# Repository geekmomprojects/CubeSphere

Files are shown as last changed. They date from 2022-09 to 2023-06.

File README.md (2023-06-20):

# The Cube Orb Project

Design files and code for a 3D printed shell to transform an LED cube of off-the shelf matrices into an illuminated sphere.

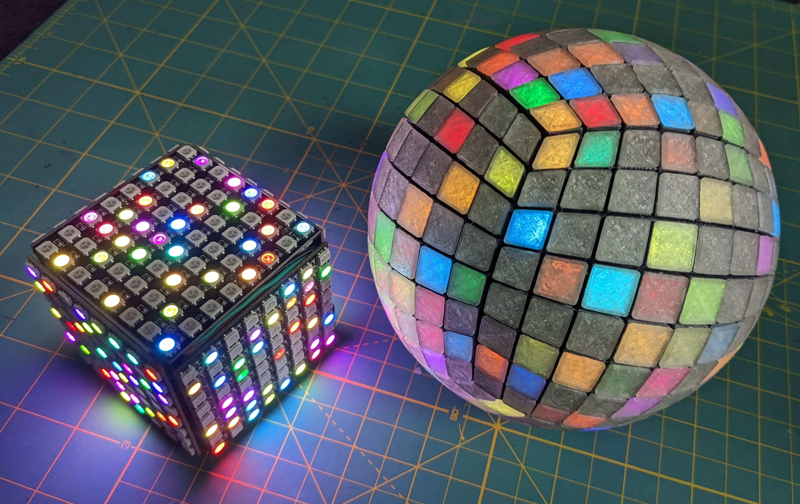
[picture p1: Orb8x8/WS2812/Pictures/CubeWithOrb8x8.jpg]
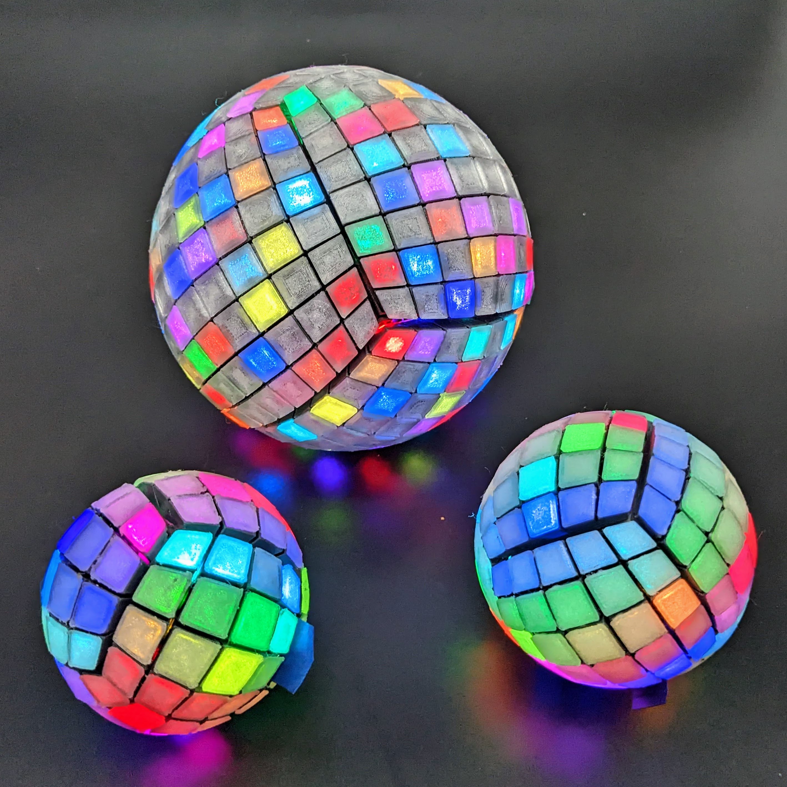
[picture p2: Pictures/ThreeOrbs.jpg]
 | 

There are multiple versions of ths project which use off-the shelf matrices of different sizes. Most use WS2812 addressable LEDs, but one version of the 8x8 orb uses SK9822 matrices. The 5x5 Orb is written up in great detail in Make: Magazine, vol. 84.

The designs, which exist in varying degrees of completion are:
- [4x4 WS2812 matrices V1](https://github.com/geekmomprojects/CubeSphere/tree/main/Orb4x4) (challenging)
- [4x4 WS2812 matrices V2 with 3D printed battery holder](https://github.com/geekmomprojects/CubeSphere/tree/main/Orb4x4_V2) (challenging)
- [5x5 WS2812 matrices](https://github.com/geekmomprojects/CubeSphere/tree/main/Orb5x5) (intermediate)
- [8x8 WS2812 matrices](https://github.com/geekmomprojects/CubeSphere/tree/main/Orb8x8/WS2812) (challenging)
- [8x8 SK9822 (APA102 equivalent) matrices](https://github.com/geekmomprojects/CubeSphere/tree/main/Orb8x8/SK9822) (intermediate)

The 8x8 orbs both use the [Pixelblaze Controller](https://electromage.com/pixelblaze) and its associated sensor board to generate pixel-mapped LEDs patterns that are sound/motion responsive. The other orb designs use the [XIAO Sense nRF52840 board](https://www.seeedstudio.com/Seeed-XIAO-BLE-Sense-nRF52840-p-5253.html) with custom CircuitPython code to control the LEDs.

For all designs, it is strongly recommended that you 3D print the cube interior connectors in PETG or other similarly strong filament. The exterior shell may be printed in PETG or PLA. You will need a well-tuned printer with good bed adhesion for this project, especially for the translucent diffusing tiles, as they require printing a large quantity of tiny parts.

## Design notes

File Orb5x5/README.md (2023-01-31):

These are design files for Cube Orb using 5x5 LED matrices. This build is documented in great detail in Vol. 84 of Make: magazine

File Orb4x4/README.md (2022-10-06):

# Cube Orb 4x4
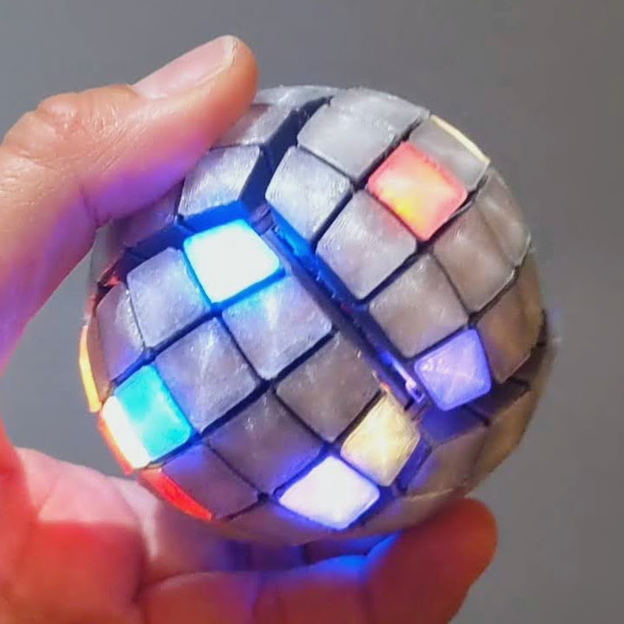
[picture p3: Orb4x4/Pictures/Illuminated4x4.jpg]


Please note that this is NOT a detailed tutorial. I have included as much information as I can to help others build
this project, but the design may still evolve, and there is likely room for improvement. It is a challenging build
because the space inside the matrix cube does not leave much room for soldering or electronics. Careful wire
management and good soldering skills will be required.

For this build, you will need the following materials:
- (6x) 4x4 WS2812 addressable LED matrices (available on Amazon or AliExpress). Size: approx 30mm square, mounting holes 15mm spacing.
- 5mm M2 flathead screws and M2 nuts
- 3D printer filament (PETG recommended for strength, I haven't tried PLA). Translucent clear filament for the tiles, and opaque filament for the shells.
- Small controller (Adafruit QtPy or Seeeduino XIAO are good choices)
- Small LiPo or LiIon battery to fit inside the matrix compartment. The largest battery I could fit inside was 250 mAh. There is also the possibility of 3D printing a battery holder for a cylindrical LiIon 14250 battery discussed further down.
- Super glue to attach tiles to the shells (Gorilla Glue Super Glue Gel highly recommended)
- Wires/solder to connect the matrices/controller/battery
- (4x) 1/4" by 1/8" disk magnets. Read paragraph below on the magnetic connectors for specifics
- 2mm wide double-sided tape (e.g. [https://www.amazon.com/gp/product/B019OQ4Z10/](https://www.amazon.com/gp/product/B019OQ4Z10/))

Start by printing each of the STL files in the [Design directory](./Design/) in the quantities included in the filename. You can buy standard 4x4 WS2812 LED matrices on Amazon or AliExpress. This design is intended for matrices that are approximately 30mm square with 4 mounting holes spaced about 15mm apart. See the [Pictures directory](/Pictures)  for images showing how the 3D printed connectors attach the matrices together.

Everything should be secured together with **5mm M2 flathead (important)** screws and nuts.

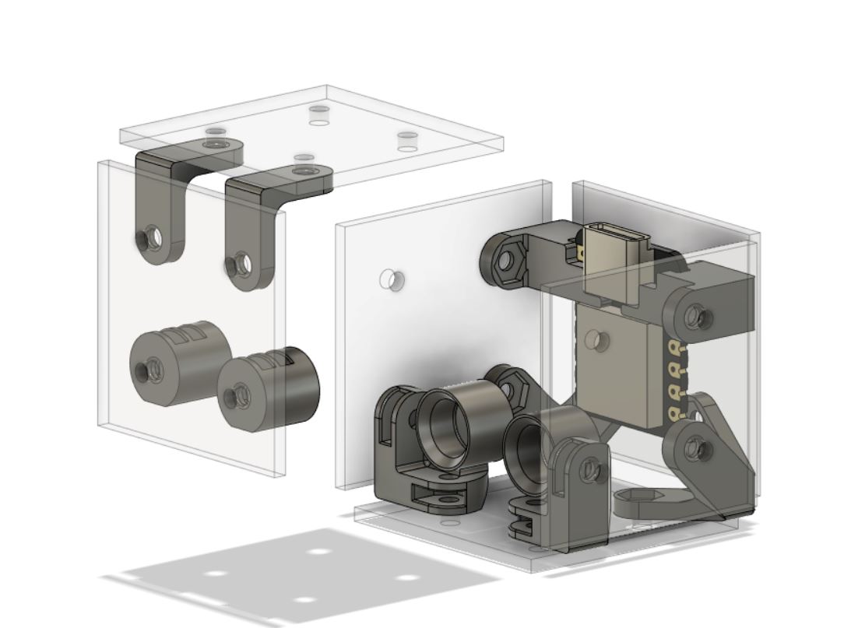
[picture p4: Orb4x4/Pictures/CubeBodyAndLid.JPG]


The supports are designed to hold an Adafruit QtPy or Seeeduino XIA0 controller inside. I am working on CircuitPython code for motion reactive LED animations using the [Seeeduino XIA0 nRF52840 Sense board](https://www.seeedstudio.com/Seeed-XIAO-BLE-Sense-nRF52840-p-5253.html), and will be uploading code to GitHub soon.

The magnetic connectors will latch the body of the cube to the lid, using cylindrical magnets with 1/4" diameter and 1/8" height. I designed the magnet holders to work with these countersunk magnet pairs from K&J magnetics (https://www.kjmagnetics.com/proddetail.asp?prod=R422CS-P-N52&cat=15f), with two pair of magnets per cube. The K&J magnets can be held in place with 5mm or 6mm (better) M2 screws and nuts. However, you can also probably buy standard 1/4" diameter, 1/8" height disk magnets and simply glue them into the holders with superglue. I haven't tried it, but I see no reason it shouldn't work.

Everything except the tiles STL should print well at 0.2mm layer height. The tiles have a bit of overhang near the top where it mushrooms out. I printed those at variable layer height with the shortest layers possible at the overhang, which helped a lot. Since there are 16 individual, small tiles in the tiles STL file, printing it can be tricky. Make SURE your first layer goes down ok. If any one of the tiles lifts off, it will ruin the whole print.

I used PETG for all the printing, because the parts are thin and small. Haven't tried it with PLA. PLA should be ok for the tiles, as they don't support anything but the rest of the pieces are small and/or thin, and will probably benefit from using PETG. Use opaque filament for the shell and transparent filament for the tiles. The brackets/holders can be printed in any color/opacity, as they will not be visible.

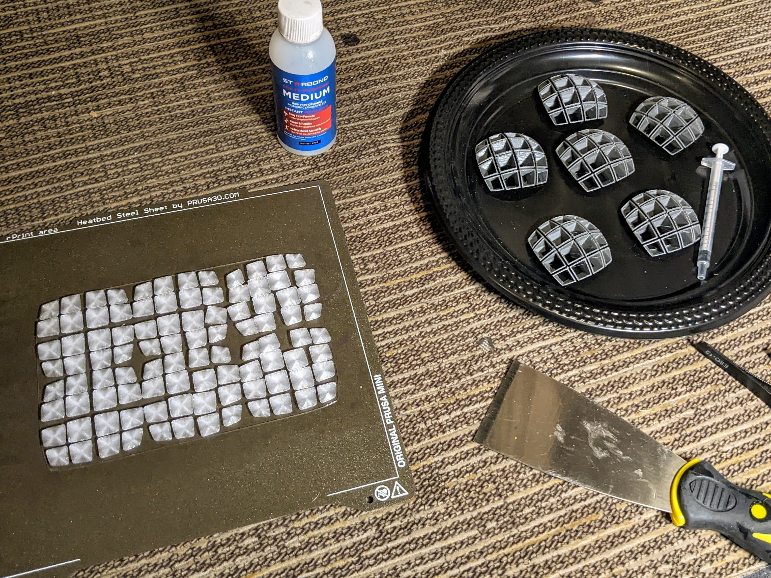
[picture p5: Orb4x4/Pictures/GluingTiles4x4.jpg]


Once printed, glue each of the tiles into the appropriate locations in the shell. Gorilla Glue Super Glue Gel strongly is recommended for this purpose. Put small beads or lines of glue in each of the holes in the top of the shell then insert each tile in the appropriate hole. Don't put the glue directly on the tile, because that's much messier (I speak from experience here!). As the tiles look nearly identical, I strongly recommend leaving them on the print plate until just before gluing each one (I loosened them row by row). Make sure to keep the orientation of each tile straight when you glue them, because it matters and it's easy to get them turned around when you lift them off the plate.

Before attaching the shell pieces to the matrix, connect the matrices into the body of the cube and the lid with the connetors as shown in the images in the [Pictures directory](./Pictures/). There are gaps between the matrices by design, as this leaves more room to put a battery inside the cube. You will probably want to solder wires between the matrices as you connect each one to its assembly because there is not a lot of room to work inside the body of the fully assembled cube.

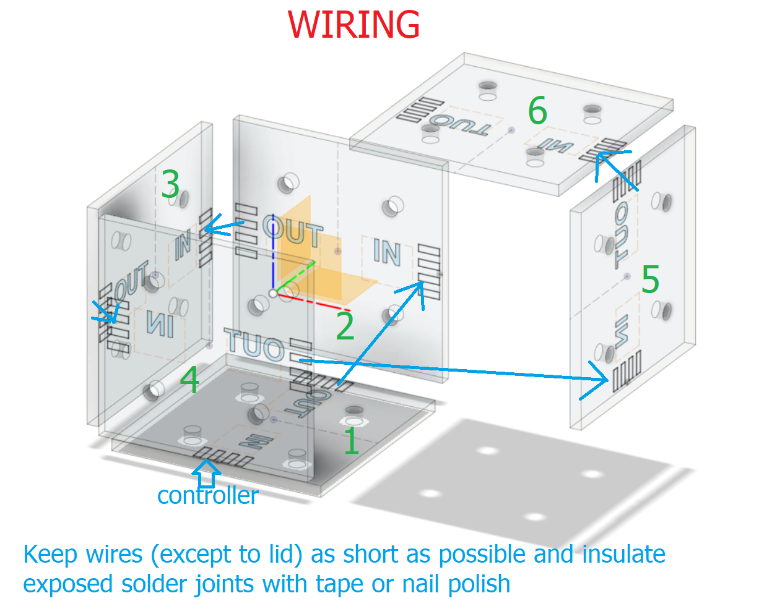
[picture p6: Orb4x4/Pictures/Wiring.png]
 

Once you have fully assembled the body and lid of the cube, you can attach the shell pieces to each matrix (after the glue for the tiles has fully dried). I placed rows and columns of 2mm wide double-sided tape along the bottom of each shell piece, then pressed each one onto a matrix. This works very well, and allows the shells to be removed if necessary. If you are certain that you won't want to remove the shells, then glue should work for this purpose as well. 

A 250 mAh LiPo battery and QTPy-sized controller should fit into the interior of the cube to power everything. Be very careful to cover the exposed pads on the LED matrices (duct tape works for this) so no shorts will occur if a nut or screw becomes loose inside the cube.

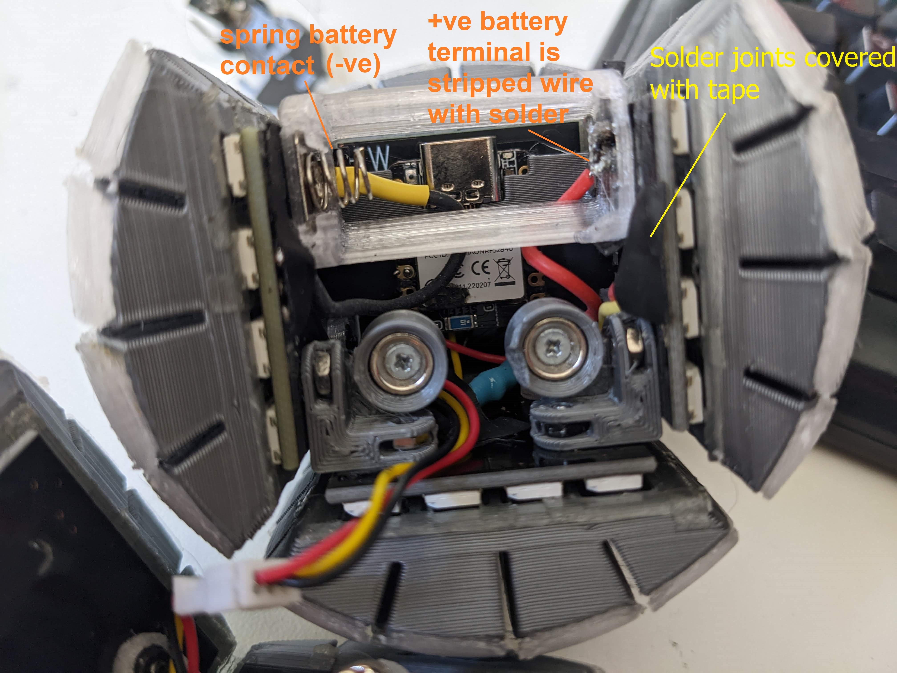
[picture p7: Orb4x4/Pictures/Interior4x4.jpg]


I have also included the (optional) design for a 14250 cylindrical LiIon battery holder which will fit inside the cube as shown in the picture below. This holder is designed to use an AAA battery spring contact no more than 10mm wide (e.g.: https://www.amazon.com/uxcell-Positive-Negative-Conversion-Nickeling/dp/B07HRS5DMC/ref=sr_1_3) for the negative battery terminal and wire wrapped around the hole in the positive terminal to run power to the electronics. More assembly instructions for the battery will follow eventually.
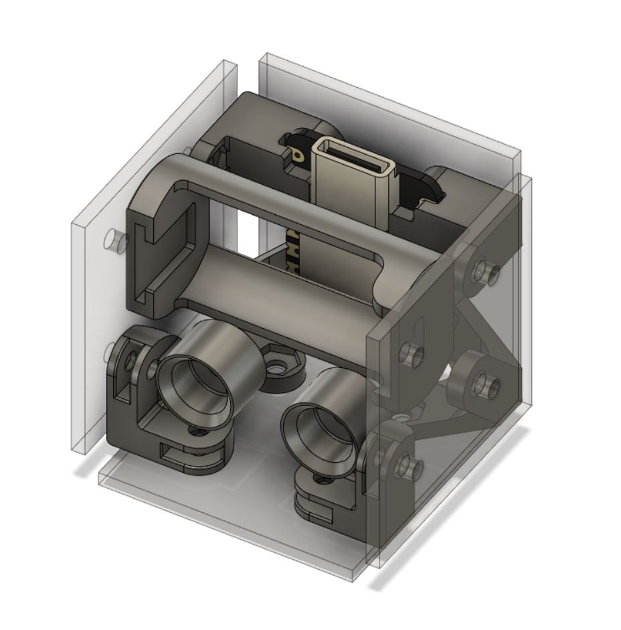
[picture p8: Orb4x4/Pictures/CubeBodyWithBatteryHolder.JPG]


Good luck! Have fun!

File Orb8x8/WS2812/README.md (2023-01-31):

# CubeSphere
Design files and code for a 3D printed shell to transform an LED cube to a sphere. This is a work in progress and the documentation and design are not complete yet. Use at your own peril.

[Follow this link for video of the sphere](https://youtube.com/shorts/eQoiFBxLnEA?feature=share)

Currently the assembly is held together with string wrapped around the parts of the shell to hold them against the matrices.

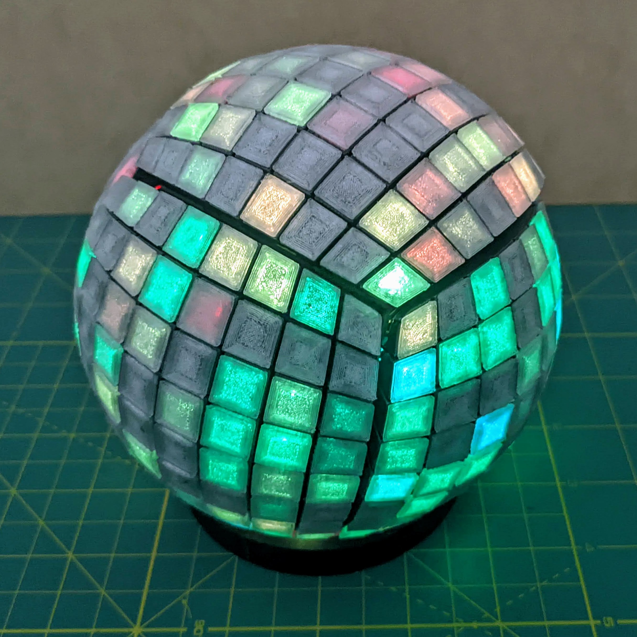
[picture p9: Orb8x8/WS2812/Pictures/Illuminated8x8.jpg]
Partially completed CubeSphere


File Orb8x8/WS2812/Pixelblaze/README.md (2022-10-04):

Please note that the map file here, written for the [Pixelblaze controller] (https://electromage.com/pixelblaze) 
reflects the following layout for the six (zigzag) WS2812 matrices in the base cube. The arrow on each side indicates the direction of the
first row on that matrix.

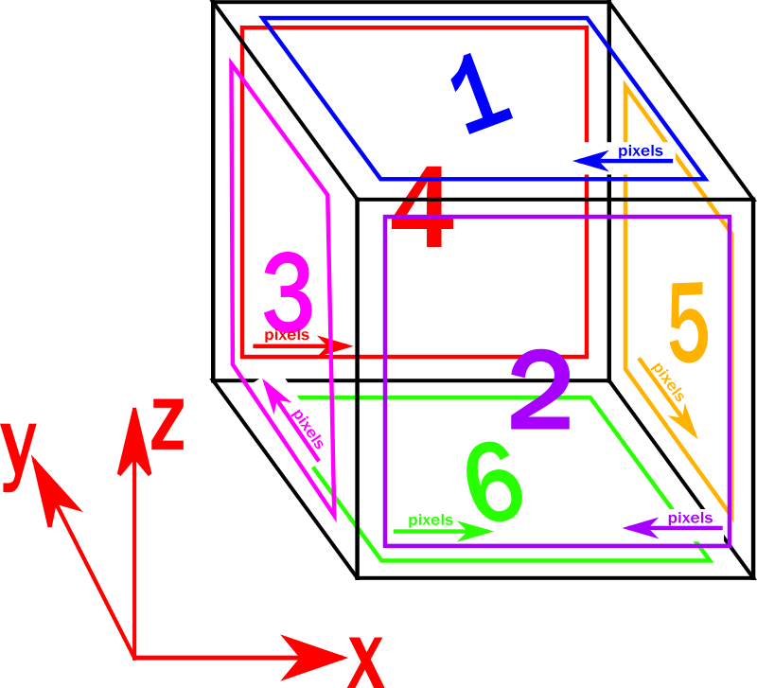
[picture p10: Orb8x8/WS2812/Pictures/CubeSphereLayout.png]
Cube Sphere matrix layout


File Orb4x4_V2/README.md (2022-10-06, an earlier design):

This version of the 4x4 orb is smaller than V1. It requires a 3D printed battery holder for 14250 cylindrical LiIon battery. Assembly instructions are not yet posted for this version.

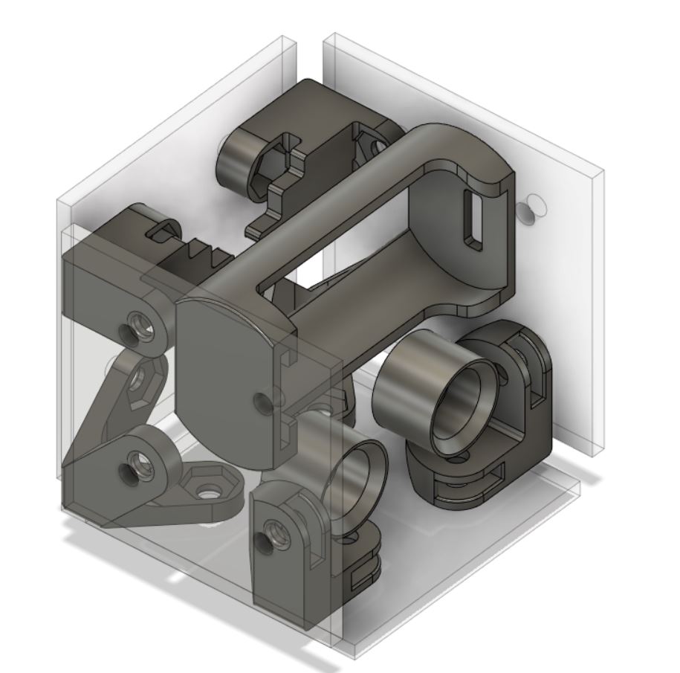
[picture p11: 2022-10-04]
Orb4x4/Pictures/BatteryHolderOrientation.JPG

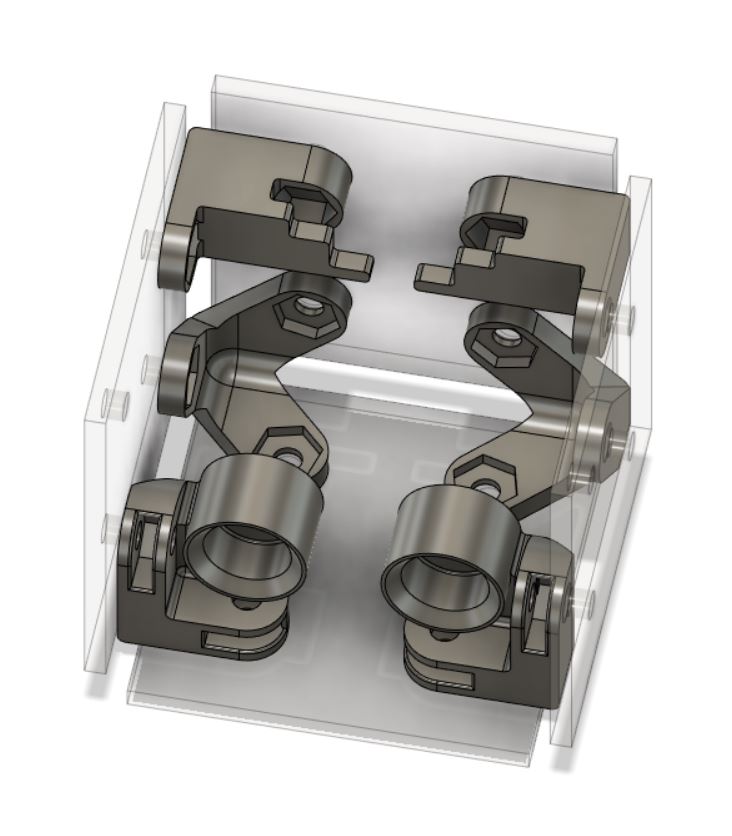
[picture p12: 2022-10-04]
Orb4x4/Pictures/CubebodyWithoutController.JPG

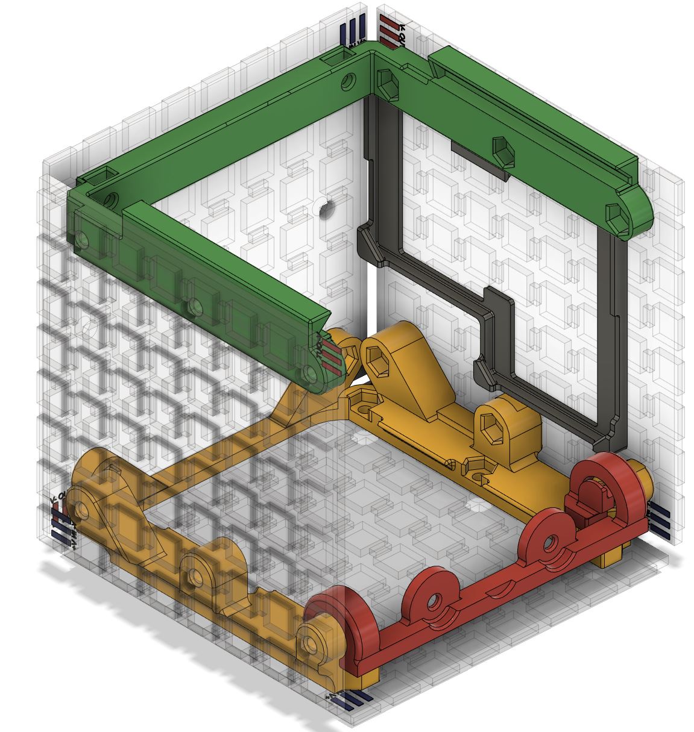
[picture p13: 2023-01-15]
Orb8x8/WS2812/Pictures/MatrixBodyWithBatteryLock.JPG

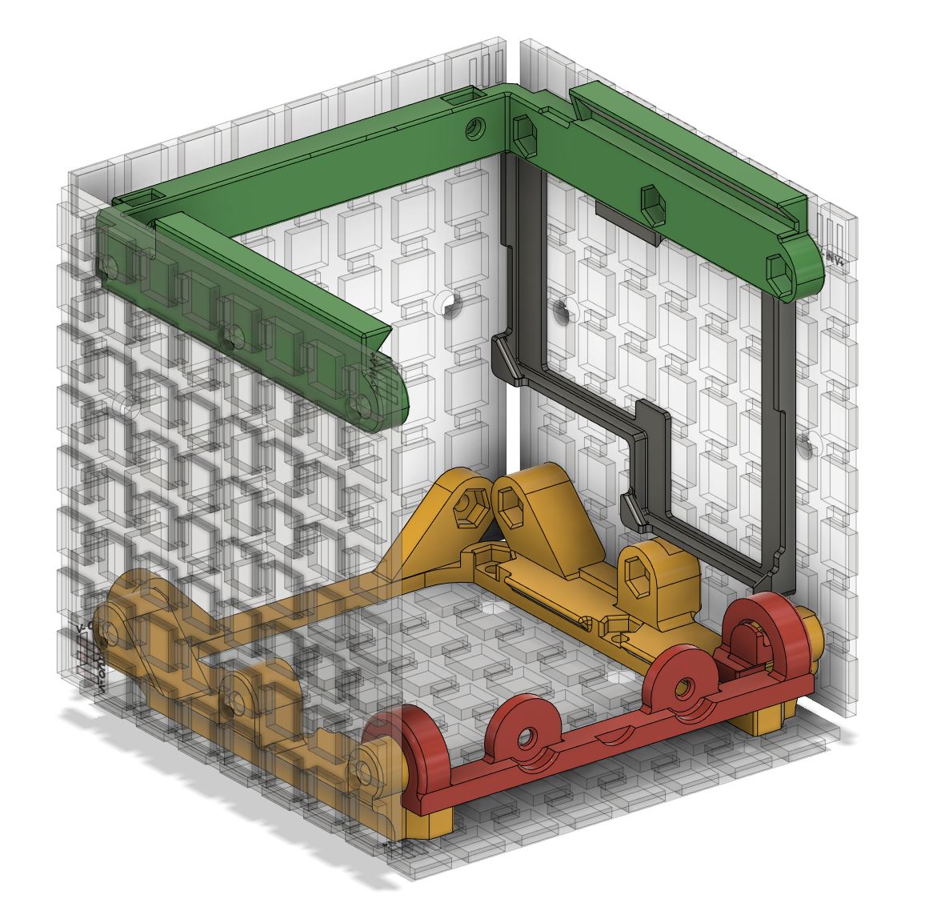
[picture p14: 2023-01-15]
Orb8x8/WS2812/Pictures/MatrixBodyConnectorsWithoutLock.JPG

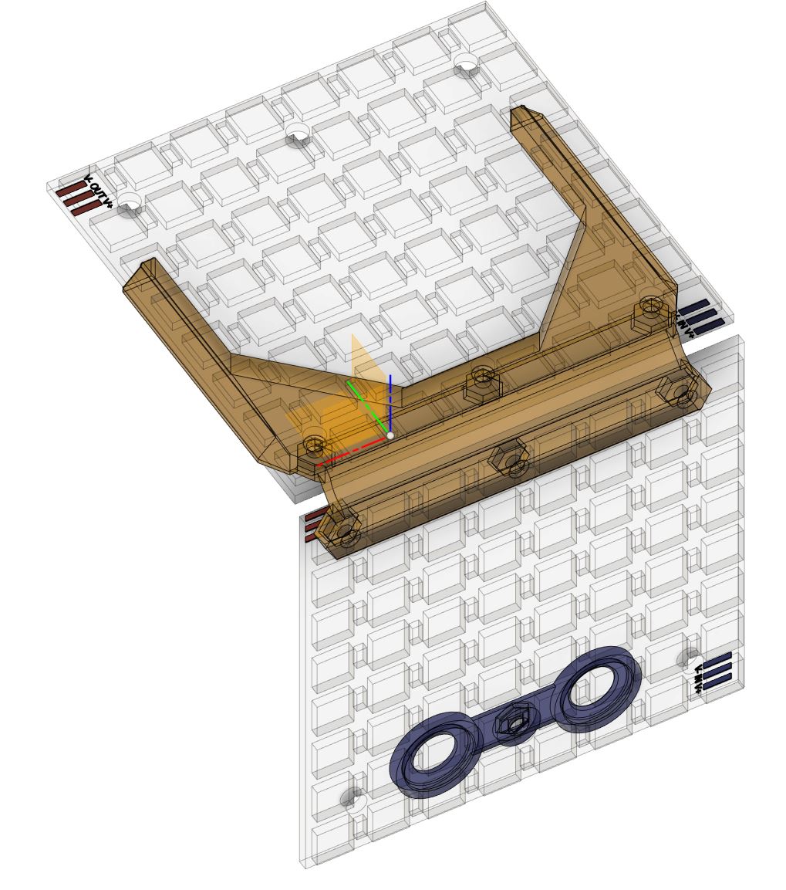
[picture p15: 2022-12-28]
Orb8x8/WS2812/Pictures/MatrixLidWithConnectors.JPG

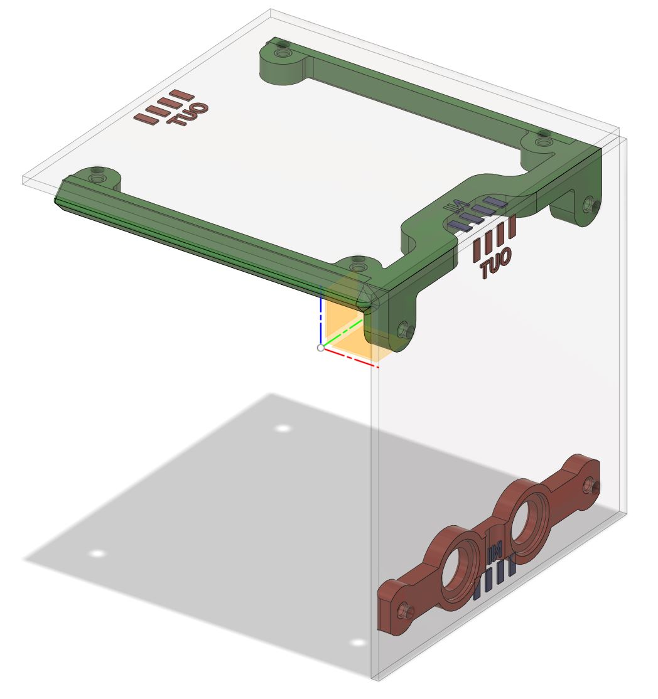
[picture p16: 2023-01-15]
Orb8x8/SK9822/Pictures/MatrixLidWithConnectors.JPG

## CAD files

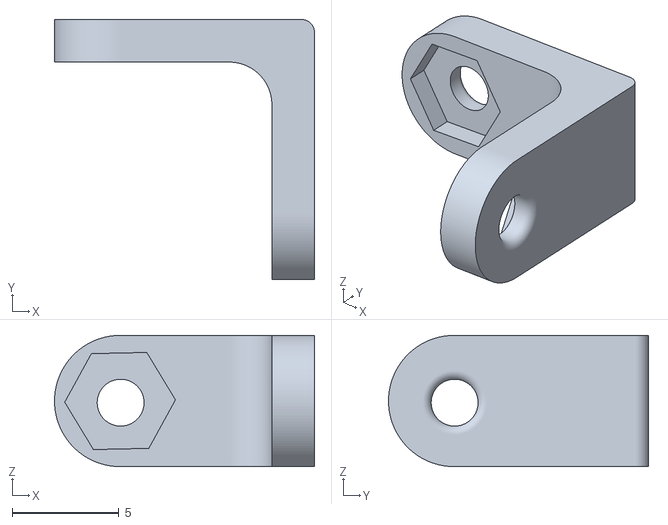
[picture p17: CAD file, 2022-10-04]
Orb4x4/Design/Side Bracket Print_2.stl
12.2 x 12.2 x 6.16

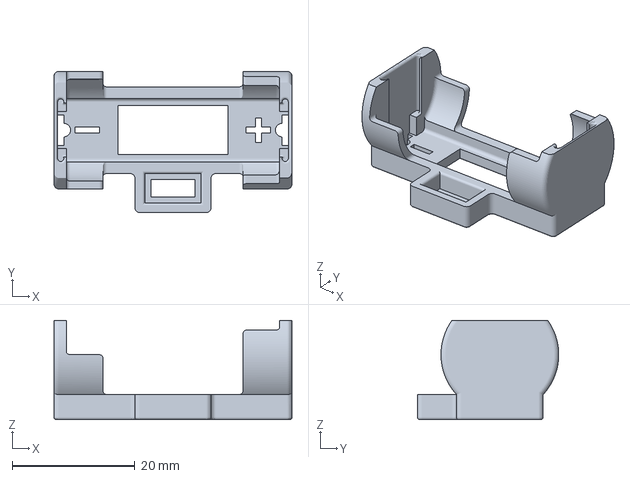
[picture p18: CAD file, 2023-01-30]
Orb5x5/Design/BatteryHolder16340Bambulag.3mf
38.8 x 23.1 x 16.2 mm

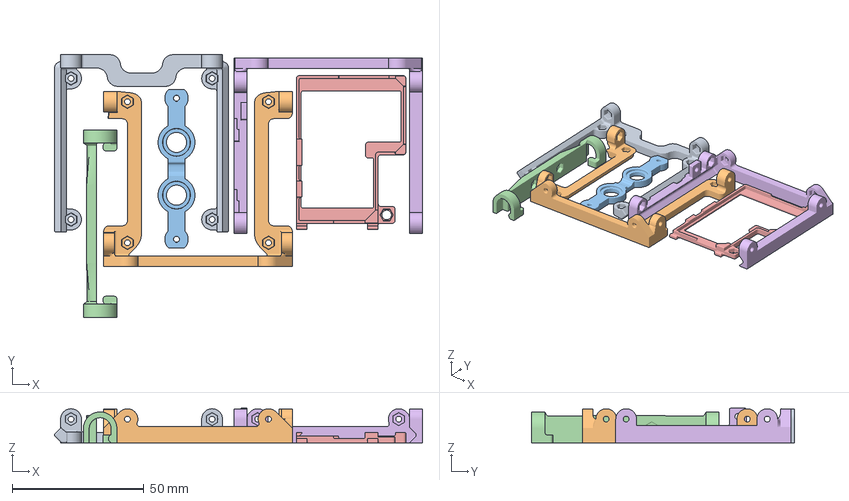
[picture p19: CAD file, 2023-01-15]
Orb8x8/SK9822/Design/CubeSphereSK9822Connectors.3mf
139.5 x 99.6 x 13.2 mm
Orb8x8 with APA102 v116.stl_1
Orb8x8 with APA102 v116.stl_2
Orb8x8 with APA102 v116.stl_3
Orb8x8 with APA102 v116.stl_4
Orb8x8 with APA102 v116.stl_5
Orb8x8 with APA102 v116.stl_6

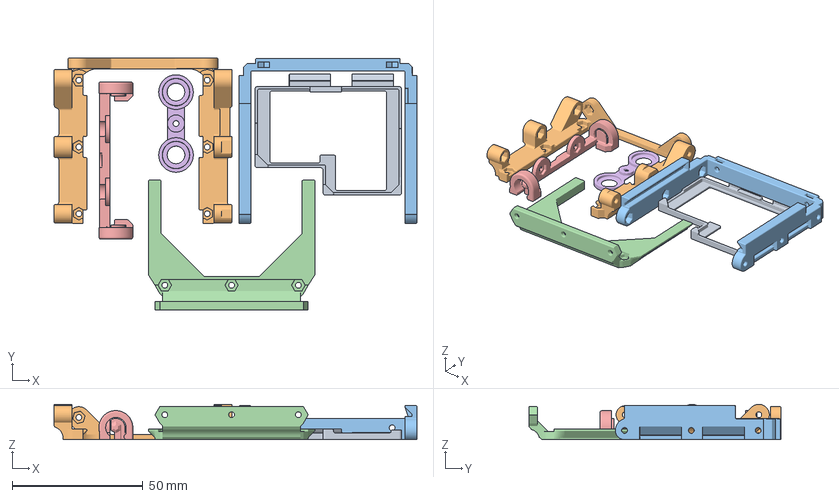
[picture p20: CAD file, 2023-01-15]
Orb8x8/WS2812/Design/CubeSphere8x8WS2812Connectors.3mf
138.6 x 96.3 x 13.5 mm
CubeSphere8x8 v194.stl_1
CubeSphere8x8 v194.stl_2
CubeSphere8x8 v194.stl_3
CubeSphere8x8 v194.stl_4
CubeSphere8x8 v194.stl_5
CubeSphere8x8 v194.stl_6

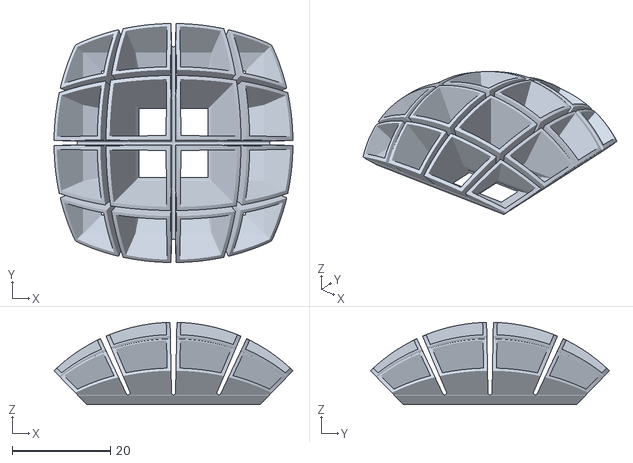
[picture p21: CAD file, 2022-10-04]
Orb4x4/Design/Shell Print_6.stl
48.8 x 48.8 x 16.8

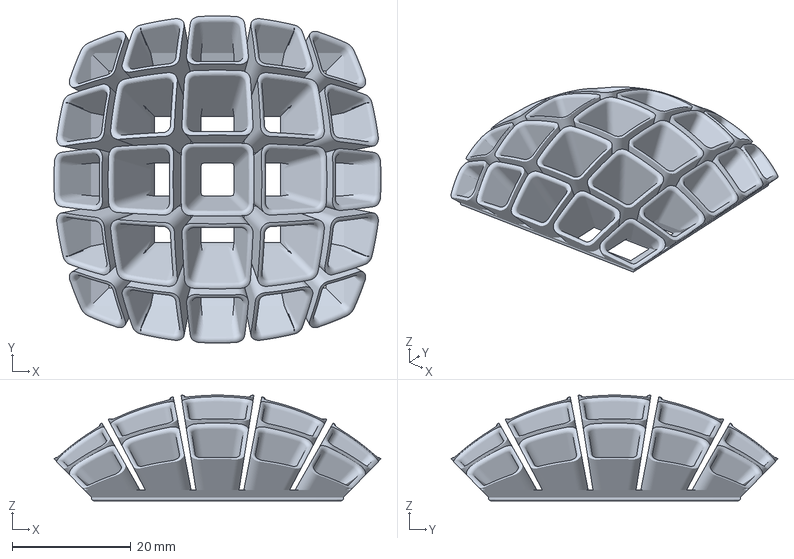
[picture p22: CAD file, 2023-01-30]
Orb5x5/Design/Shell5x5BambulabSlicer.3mf
55.1 x 55.1 x 17.8 mm

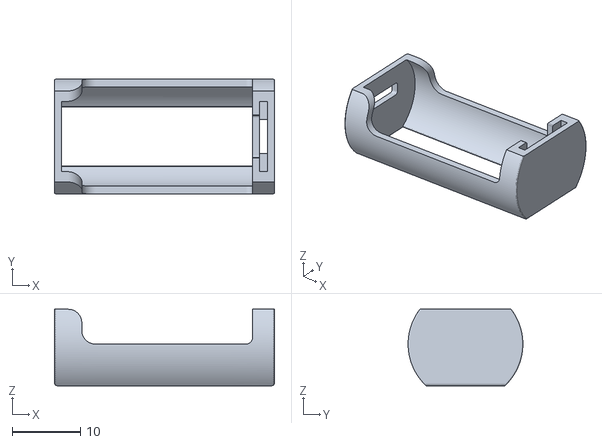
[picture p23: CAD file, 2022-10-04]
Orb4x4/Design/BatteryHolder14250.stl
32.2 x 16.8 x 11.2

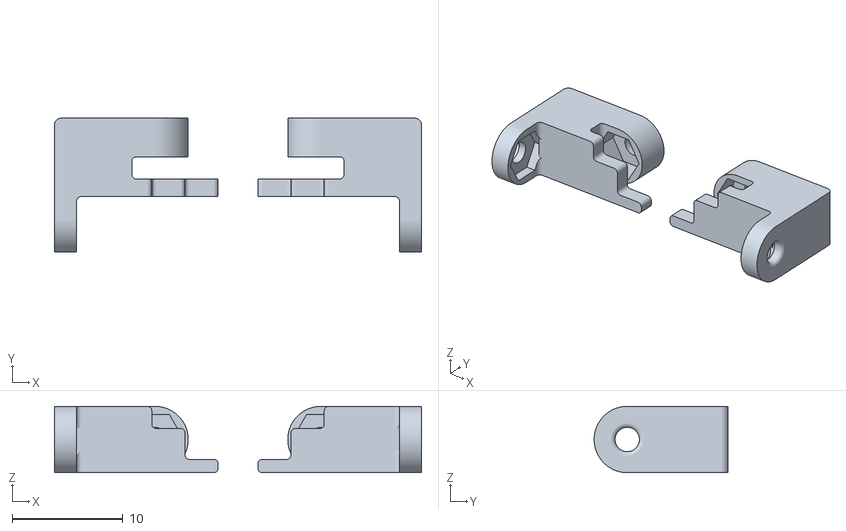
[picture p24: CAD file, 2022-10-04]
Orb4x4/Design/Side Bracket Xiao Holder Print_1.stl
33.2 x 12.1 x 6.00

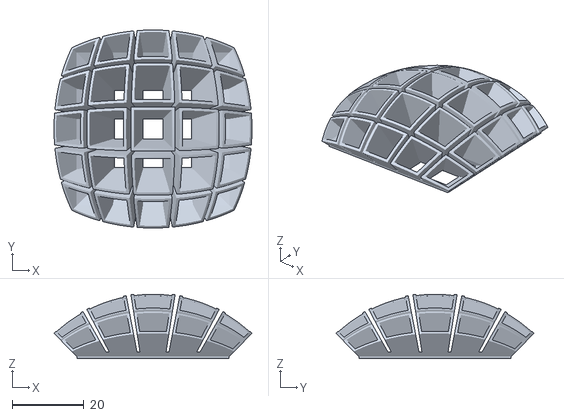
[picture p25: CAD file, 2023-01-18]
Orb5x5/Design/Shell5x5.stl
55.1 x 55.1 x 17.9

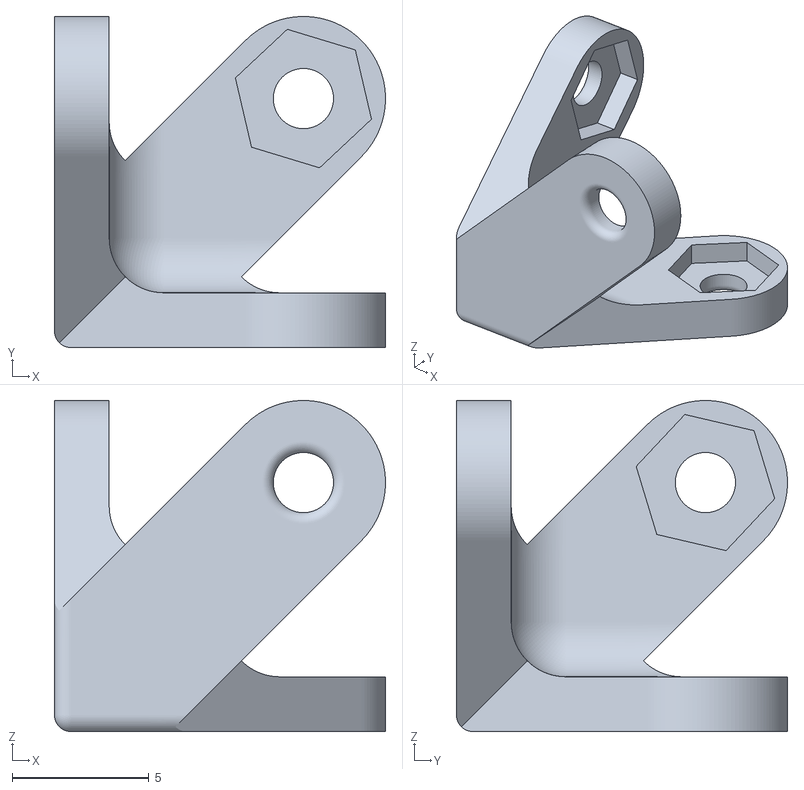
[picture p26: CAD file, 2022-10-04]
Orb4x4/Design/Corner Bracket Print_2.stl
12.1 x 12.1 x 12.1

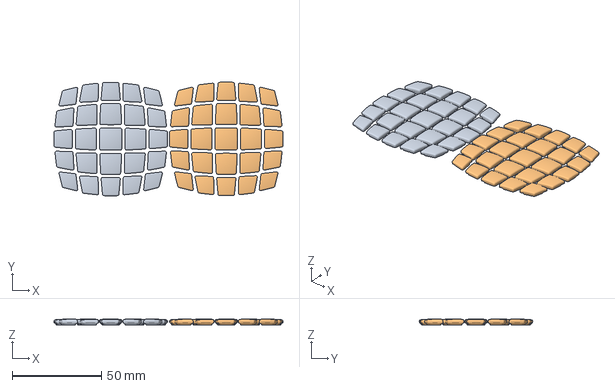
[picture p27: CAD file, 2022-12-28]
Orb5x5/Design/Tiles5x5Thinner.3mf
128.4 x 63.7 x 3.58 mm

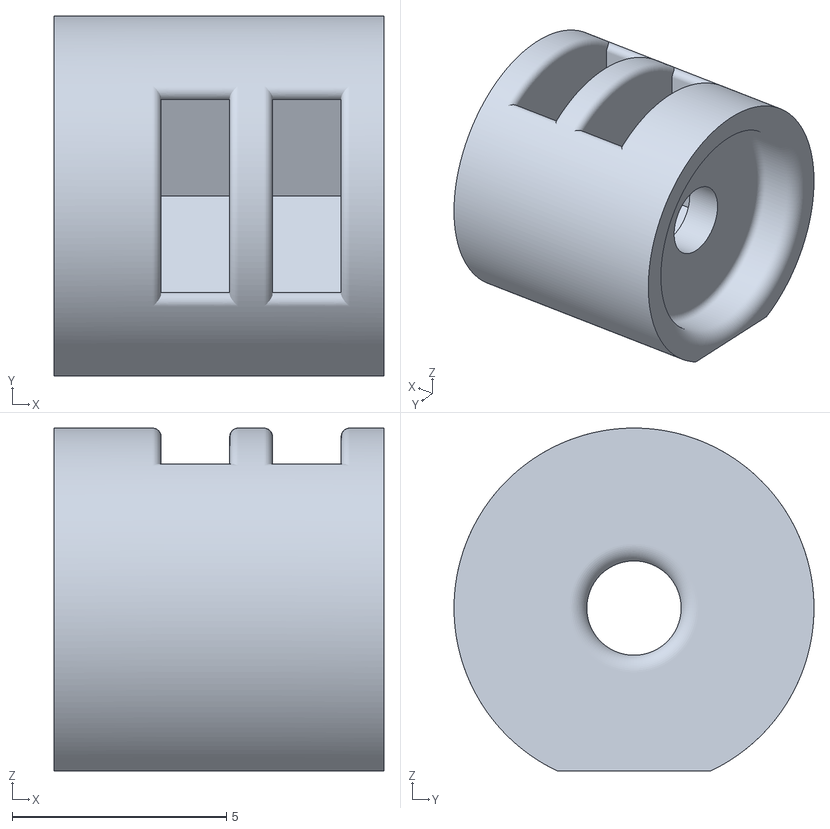
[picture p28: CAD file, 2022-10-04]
Orb4x4/Design/Magnet Holder Lid Print_2.stl
7.70 x 8.40 x 8.00

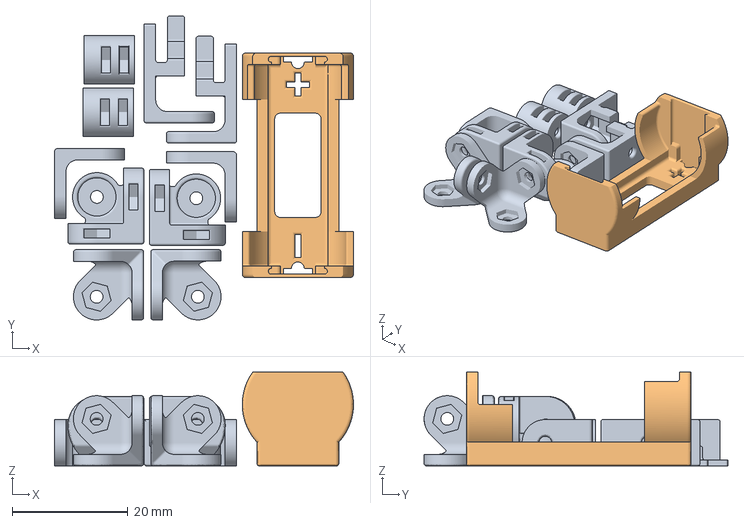
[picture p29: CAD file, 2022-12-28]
Orb5x5/Design/AllConnectors5x5.3mf
51.6 x 52.5 x 16.2 mm
AllConnectors5x5.stl
BatteryHolder16340.stl

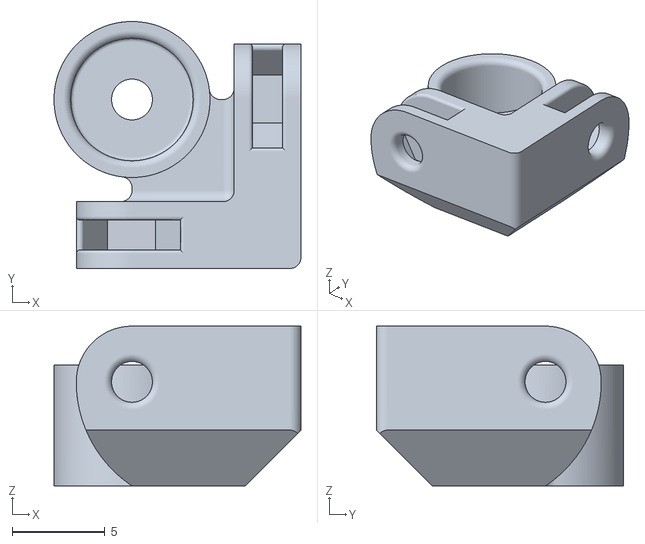
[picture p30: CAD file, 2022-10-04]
Orb4x4/Design/Magnet Holder Body Print_2.stl
13.3 x 13.3 x 8.60

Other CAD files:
Orb5x5/Design/BatteryHolder16340WithSwitch.stl
Orb5x5/Design/BatteryHolder16340.stl
Orb4x4_V2/Design/BatHolder.stl
Orb4x4_V2/Design/Shell4x4V2.stl

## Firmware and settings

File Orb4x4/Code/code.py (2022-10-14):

# Write your code here :-)
from tilt import Tilt
from adafruit_led_animation.animation.rainbowsparkle import RainbowSparkle
from adafruit_led_animation.color import RAINBOW
from bubbles import Bubbles
from orb import *
import imu
import board
import neopixel
import time, random

RED = (255,0,0)
BLACK = (0,0,0)

# Update to match the pin connected to your NeoPixels
pixel_pin = board.D4
# Update to match the number of NeoPixels you have connected
pixel_num = 96

pixels = neopixel.NeoPixel(pixel_pin, pixel_num, brightness=0.3, auto_write=False)
pixels.fill((0,0,0))

def orb4x4():
    width = 4
    gap = 0.25
    X = Matrix.X
    Y = Matrix.Y
    Z = Matrix.Z
    npix = width*width
    maxv = width-1 #largest coordinate valhe
    #definition of matrix defaults to alternating rows
    #The reference coodrinate frame for the orb is the one in which the
    #XIAO X-axis is along the short board axis, the positive Y axis is along
    #the long axis with positive direction pointed towards the USB connector
    #and positive Z axis is above the top of the board

    #Standard matrix with alternating row directions
    front = Matrix([0, -gap, 0], X, Z, 0, width)
    right = Matrix([maxv + gap, 0, maxv], -Z, Y, 1*npix, width)
    bottom = Matrix([maxv, 0, -gap], -X, Y, 2*npix, width)
    left = Matrix([-gap, 0, 0], Z, Y, 3*npix, width)
    top = Matrix([maxv, 0, maxv+gap], Y, -X, 4*npix, width)
    back = Matrix([maxv, maxv+gap, maxv], -Z, -X, 5*npix, width)
    """
    # This is my weird cube with some alternating, some non-alternating matrices
    front = Matrix([0, -gap, 0], X, Z, 0, width, alternating=False)
    right = Matrix([maxv + gap, 0, maxv], -Z, Y, 1*npix, width, alternating=False)
    bottom = Matrix([maxv, maxv, -gap], -X, -Y, 2*npix, width, alternating=True)
    left = Matrix([-gap, maxv, 0], Z, -Y, 3*npix, width, alternating=True)
    top = Matrix([maxv, 0, maxv+gap], Y, -X, 4*npix, width, alternating=False)
    back = Matrix([maxv, maxv+gap, maxv], -Z, -X, 5*npix, width, alternating=False)
    """
    orb = Orb(width,[front, right, bottom, left, top, back],
                ["front", "right", "bottom", "left", "top", "back"], pixels)
    return orb

#Create orb object
orb=orb4x4()

#useful when mapping the layout of the pixels in each matrix
def do_pixel(color=RED):
    for i in range(pixel_num):
        pixels[i] = color
        pixels.show()
        pixels[i] = BLACK
        time.sleep(0.1)

def do_matrix(color=RED):
    for i in range(6):
        name = orb.matrix_name(i)
        orb.fill_matrix(i,color)
        time.sleep(.5)
        orb.fill_matrix(i, BLACK)

def fill_half(coord=0, color=RED):
    for i in range(pixel_num):
        if orb.cart[i][coord] > 0.05:
            pixels[i] = color
        else:
            pixels[i] = BLACK


imu = imu.IMU()
tilt = Tilt(orb.pixels, orb.cart, imu)
bubbles = Bubbles(orb.pixels, orb.spher, imu, color=RED)
rainbow_sparkle = RainbowSparkle(pixels, speed = 0.075, step=10, period=20, num_sparkles = 30, background_brightness = 0)

while True:
    #do_pixel()
    tilt.animate()
    #rainbow_sparkle.animate()
    #bubbles.animate()

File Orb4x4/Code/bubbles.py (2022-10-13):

from adafruit_led_animation.animation import Animation
from coordinates import *
import board, time
import math
import random

#NOTE: Work in progress. Currently doesn't make use of the IMU, but will eventually
# move the bubbles around so they float to the top of the orb

#returns angular distance between two angular positions
def angular_separation(theta1, phi1, theta2, phi2):
    return math.acos(math.cos(phi1)*math.cos(phi2) +
                     math.sin(phi1)*math.sin(phi2)*math.cos(theta1 - theta2))

class Bubble:
    def __init__(self, radius, color, pos):
        # radius is angular in radians
        self.radius = radius
        self.color = color
        #position on the surface of a sphere, theta, phi
        self.pos = pos
        self.velocity = [random.random()/20, random.random()/20]

class Bubbles(Animation):
    """
    Tilt Animation
    :param pixel_object: The initialised LED object.
    :param float speed: Animation speed in seconds, e.g. ``0.1``.
    :param color: Animation color in ``(r, g, b)`` tuple, or ``0x000000`` hex format.
    :param twinklechance: chance of turning on at any moment
    """
    def __init__(
        self,
        pixel_object,
        coord_list,  #Angular coordinates (r, theta, phi)
        imu,
        speed=.03,
        color=(255,0,0),
        name=None
    ):
        super().__init__(pixel_object, speed, color=color, name=name)
        self.imu = imu
        self.coords = coord_list
        self.bubbles = [Bubble(math.pi/4, (255,0,0), [math.pi/5,math.pi/8]),
                        Bubble(math.pi/4, (0,255,0), [math.pi/3, math.pi/9]),
                        Bubble(math.pi/5, (0,0,255), [-math.pi/3, 0])]


    def reset(self):
        self.pixel_object.fill((0,0,0))

    # Base color on pitch, position on roll
    def draw(self):
        x,y,z = self.imu.acceleration
        pitch = math.atan2(x,z)
        roll = math.atan2(y, math.sqrt(z*z + x*x))
        #print("Acceleration: X:%.2f, Y: %.2f, Z: %.2f m/s^2" % (self.imu.acceleration))
        #print("Gyro X:%.2f, Y: %.2f, Z: %.2f radians/s" % (imu.gyro))
        #print("Pitch:%.2f, Roll:%.2f" % (pitch, roll))
        #droll = math.degrees(roll)
        #dpitch = math.degrees(pitch)
        #print(" roll ",droll, " pitch ", dpitch)
        npix = self.pixel_object.n
        self.pixel_object.fill((0,0,0))
        for i in range(npix):
            for b in self.bubbles:
                sep = angular_separation(b.pos[0], b.pos[1], self.coords[i][0], self.coords[i][1])
                if sep < b.radius:
                    v = math.pow((1-sep/b.radius),2)
                    self.pixel_object[i] = [int(self.pixel_object[i][k] + b.color[k]*v) for k in range(3)]

        for b in self.bubbles:
            b.pos[1] += b.velocity[1]
            if b.pos[1] >= math.pi:
                b.pos[1] = math.pi - b.pos[1]
                b.velocity[1] = -b.velocity[1]
            b.pos[0] += b.velocity[0]
            if b.pos[0] >= math.pi:
                b.pos[0] -= 2*math.pi

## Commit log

2022-09-10 Add fusion 360 and design files
    [Exterior.stl, Interior.stl, Whole.stl]
2022-09-15 Added print files for tiles/Design files for tiles/cube frame
    [InnerFrame.f3d, PrintableTiles.f3d]
2022-10-04 Reorganized and added files for 4x4 orb
    [BatteryHolder14250.stl, Corner Bracket Print_2.stl, Exterior.stl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]
2022-10-06 Added STL files for smaller 4x4 cube and 5x5 cube
    [BatHolder.stl, BatteryHolder16340.stl, Shell4x4V2.stl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]
2022-10-13 Added Code for 5x5 Orb
    Circuit python code to use the IMU in the XIAO nRF52840 Sense board to run animations based on the CircuitPython led_animation library
2022-10-14 Uploaded Circuitpython code for 4x4 orb (original version_)
2022-12-28 Updated 8x8 Cube Files
    Broke out the 8x8 build for WS2812 and (soon to come) SK9822 Matrices and uploaded the latest STL files for the 8x8 WS2812 build
    [AllConnectors5x5.3mf, Exterior.stl, InnerFrame.f3d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]
2023-01-15 New SK9822 8X8 files, Modified WS2812 8x8 design
    [CubeSphere8x8WS2812Connectors.3mf, CubeSphereSK9822Connectors.3mf]
2023-01-18 Added pointy tiles for 5x5 cube design
    [BatteryHolder16340WithSwitch.stl, Shell5x5.stl]
2023-01-30 Add sliced files
    [BatteryHolder16340Bambulab.3mf, Shell5x5BambulabSlicer.3mf]
2023-01-30 New pictures
    [BatteryHolder16340Bambulag.3mf]
2023-12-16 Add alternate layout comment
    With my 5x5 LEDs I found the starting points different than was was configured. Adding a comment for other folks that my have the same problem.
    [code.py]
